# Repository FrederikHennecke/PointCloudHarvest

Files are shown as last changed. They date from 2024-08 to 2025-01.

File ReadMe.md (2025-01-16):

# PointCloudHarvest (FarmBot Stereo-Vision Camera Module for Leaf Angle Calculation)

## Motivation
Leaf inclination angles (LIA) are crucial for regulating various processes within the plant carbon–water–energy nexus. In agriculture, these processes include photosynthesis, leaf temperature, plant growth, and the microclimate within the canopy. Despite its significance, LIA remains one of the most understudied plant functional traits due to the difficulty of measuring it accurately, particularly at short temporal intervals. In optical remote sensing, LIA is a key factor influencing spectral variability, which directly impacts the robustness of empirical models. We developed a novel and automated approach to capture 3D point clouds of small crops (e.g., sugar beet), enabling precise determination of LIA from the generated data. Our system, controlled by publicly available code, allows for customizable capture intervals and positions. The method was validated using a 3D-printed sugar beet model with known LIA, demonstrating its potential for advancing plant trait studies.

farmbot

This project implements a module for the FarmBot that uses a stereo-vision camera to take point clouds of sugar beet plants and calculate their leaf angles. The module consists of scripts for recording plant data and generating point clouds from these recordings.

## Project Structure

- [`record/`](record/): Contains Python for recording the plants.
- [`reconstruction_system/`](reconstruction_system/): Contains Python files for creating point clouds from the recordings.
- [`farmbot_files`](farmbot_files/): Contains LUA files. Add the file to the FarmBot web interface.
- [`data/`](data/): Contains example point clouds each generated with this project.
- [`images/`](images/): Contains images used in this repository.
- [`printing_files/`](printing_files/): Contains CAD files used for the project. May be used to 3d print the camera bracket.

## Build Instructions
See [`hardware-setup.md`](hardware-setup.md)).

## Installation

Each folder ([`record/`](record/), [`reconstruction_system/`](reconstruction_system/), [`farmbot_files`](farmbot_files/)) has it's own installation instructions.

## Usage

### Recording Plant Data

- Navigate to the [`record/`](record/) directory and run the appropriate scripts on the camera module (Raspberry Pi).
- Navigate to the [`farmbot_files`](farmbot_files/) directory and copy the LUA file to the farmbot web interface.

### Generating Point Clouds

Navigate to the [`reconstruction_system/`](reconstruction_system/) directory and run the scripts to create point clouds from the recordings.

## Acknowledgements

Many files from the [Open3D documentation](http://www.open3d.org/docs/release/) were used in this project.

## License

This project is licensed under the MIT License - see the [LICENSE](LICENSE) file for details.

## Citation

Please cite [our work](https://doi.org/10.1016/j.mex.2025.103169) if you use this software.
```bibtex
@article{Hennecke_Modification_of_an_2025,
    author  = {Hennecke, Frederik and Bömer, Jonas and Heim, René H.J.},
    doi     = {10.1016/j.mex.2025.103169},
    journal = {MethodsX},
    month   = jan,
    title   = {{Modification of an Automated Precision Farming Robot for High Temporal Resolution Measurement of Leaf Angle Dynamics using Stereo Vision}},
    url     = {http://dx.doi.org/10.1016/j.mex.2025.103169},
    year    = {2025}
}
```

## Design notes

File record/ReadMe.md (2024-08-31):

# RealSense Angle Measurement Software

This software is designed to capture and analyze angles using a RealSense camera on a Raspberry Pi.

## Prerequisites

### Librealsense

Librealsense is a cross-platform library for capturing data from Intel RealSense depth cameras.

To install Librealsense, follow these steps:

1. Install the prerequisites:

   - On Ubuntu:
     ```bash
     sudo apt-get update && sudo apt-get upgrade
     sudo apt-get install git cmake libssl-dev libusb-1.0-0-dev pkg-config libgtk-3-dev
     ```

   - On Windows:
     Download and install [Visual Studio](https://visualstudio.microsoft.com/) and [CMake](https://cmake.org/download/).

2. Clone the librealsense repository:

   ```bash
   git clone https://github.com/IntelRealSense/librealsense.git
   cd librealsense
   ```

3. Build and install the library:

   - On Ubuntu:
     ```bash
     mkdir build && cd build
     cmake ../ -DBUILD_EXAMPLES=true
     make && sudo make install
     ```

   - On Windows:
     Follow the instructions in the `librealsense` [documentation](https://github.com/IntelRealSense/librealsense/blob/master/doc/installation_windows.md).

### Python

1. **Install Python 3**: Ensure Python 3 is installed on your Raspberry Pi.

2. **Install RealSense Library**:
   - You need to install the RealSense library (`librealsense2`) on your Raspberry Pi.
   - Follow the official [Intel RealSense installation guide](https://github.com/IntelRealSense/librealsense/blob/master/doc/installation.md) for instructions specific to your platform.

3. **Install Python Dependencies**:
   - After installing `librealsense2`, install the required Python dependencies. This includes the RealSense Python wrapper.

   ```bash
   pip install opencv-python
   pip install pyrealsense2
   ```

## Installation

1. **Clone the Repository**:
   - Download the software to your Raspberry Pi by cloning the repository or copying the files.

   ```bash
   git clone <repository-url>
   cd <repository-directory>
   ```

2. **Run the Software**:
   - To start capturing and analyzing angles, run the `main.py` script.

   ```bash
   python3 main.py
   ```

## Usage

Once the software is running, it will automatically begin capturing depth images, whenever it gets a signal via UART.

## Troubleshooting

- Ensure that the RealSense camera is properly connected to the Raspberry Pi.
- Make sure `librealsense2` and `pyrealsense2` are correctly installed.
- If you encounter any errors, check the dependencies and ensure all required libraries are installed.

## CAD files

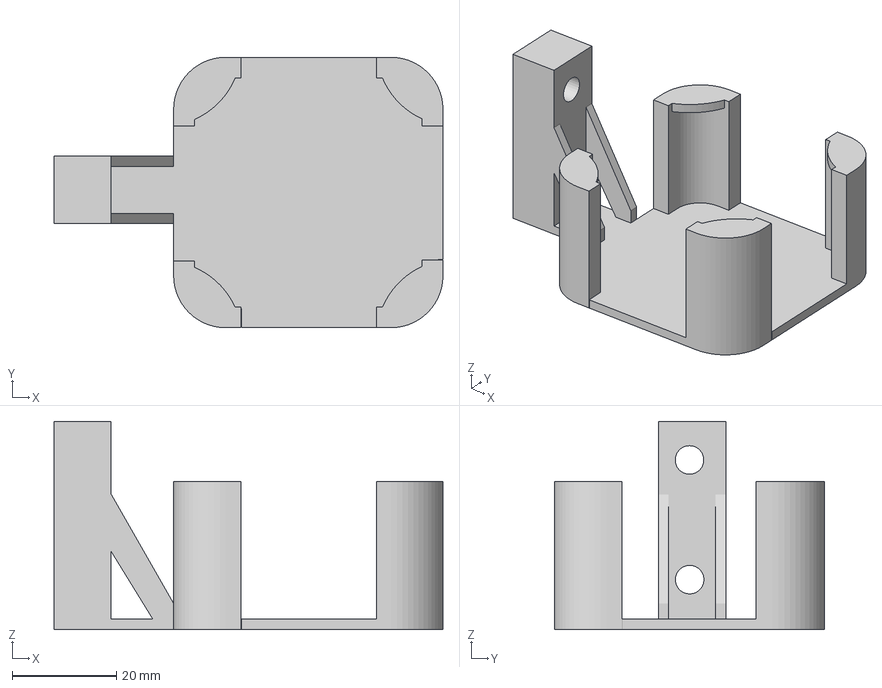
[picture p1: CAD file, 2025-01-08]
printing_files/D405_Bracket.3mf
74.8 x 52.0 x 40.0 mm

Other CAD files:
data/1_3.ply
data/1_2.ply
data/6_2.ply
data/1_1.ply
data/3_2.ply
data/3_3.ply
data/6_1.ply
data/6_3.ply
data/3_1.ply
printing_files/D405_Bracket.f3d

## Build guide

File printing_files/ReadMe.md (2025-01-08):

The CAD files of the Realsense D405 camera can be found on the [official intel realsense website](https://dev.intelrealsense.com/docs/stereo-depth-camera-d400#section-cad-files).

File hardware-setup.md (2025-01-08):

# List of Materials
- Any [FarmBot](https://farm.bot/)
- [Raspberry Pi 4b 8GB](https://www.raspberrypi.com/products/raspberry-pi-4-model-b/?variant=raspberry-pi-4-model-b-8gb) - not the one from the FarmBot, but a different one
  - Raspberry Pi Mount (see [here](https://a.co/d/2Kd7VHw) for a waterproof container)
  - micro-SD 64GB
  - Any power supply for the Raspberry Pi like the USB-C supply.
- [Intel Realsense D405](https://www.intelrealsense.com/depth-camera-d405/)
  - Long USB cable (D405 needs a [Micro B](https://amzn.eu/d/33nk2e9)) for the camera. Should be at least 2m for a 1.5m FarmBot.
  - Camera Mount (see [`printing_files/`](printing_files/))
- External SSD (with USB connector) for saving all depth images.
- Cable to connect the Raspberry Pi UART
  - Ex: female to female jumper wire
  - Length is dependent on your mount location of the Raspberry Pi

# Setup
farmbot
1. Build the FarmBot
   - While adding the cables to the cable carries of the cross-slide and z-axis, also add the USB cable to the carries.
2. Add the camera to the main gantry using the camera mount.
   - It should face downward. It can have an offset.
   - Connect the camera to the USB cable previously installed.
3. Add the Raspberry Pi with its mount.
4. Connect the Raspberry Pi to the USB cable and to the PSU.
5. Connect the Raspberry Pi to the Raspberry Pi in the electronics box of the FarmBot via UART.
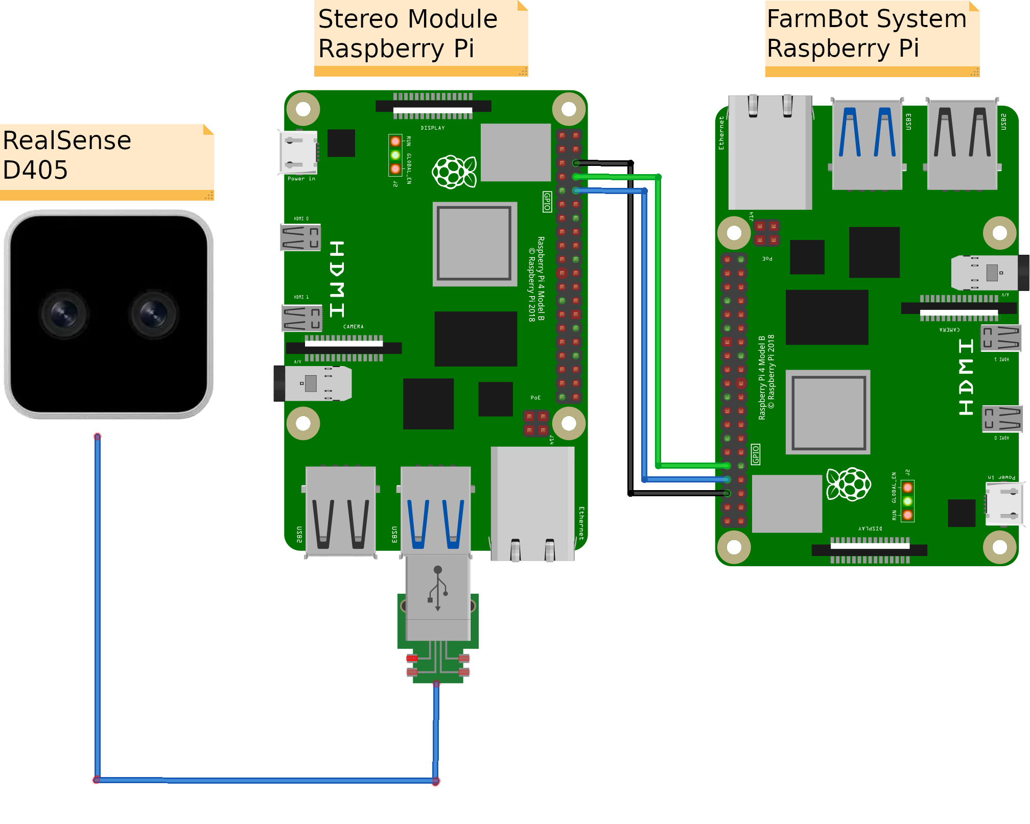
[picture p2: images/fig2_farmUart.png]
UART

6. Install any OS on the micro-SD card (Raspian is recommended).
7. Put the micro-SD card into the Raspberry Pi.
8. Connect the external SSD to the Raspberry Pi.
9. Connect the Raspberry Pi to its power supply.
10. Mount the SSD ([see](https://raspberrypi-guide.github.io/filesharing/mounting-external-drive)).
11. Follow the software installation instruction in [`reconstruction_system/`](reconstruction_system/) and [`farmbot_files`](farmbot_files/).

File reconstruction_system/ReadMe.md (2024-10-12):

# Open3D Reconstruction System

This software provides a flexible system for reconstructing 3D models from RGBD sequences using Open3D. You can control various stages of the reconstruction process through command-line arguments.

## Prerequisites

1. **Install Python 3**: Ensure Python 3 is installed on your system.

2. **Install Required Libraries**:
   - Install Open3D and other necessary Python libraries:

   ```bash
   pip install opencv-python
   pip install open3d
   ```
(See [here](https://www.open3d.org/docs/release/getting_started.html) for help using Open3D)
## Installation

1. **Clone the Repository**:
   - Download the software to your local machine:

   ```bash
   git clone <repository-url>
   cd <repository-directory>
   ```

2. **Install the Software**:
   - If there are any additional setup steps or dependencies, follow the instructions provided in the repository.

## Usage

```bash
python3 main.py [OPTIONS]
```

### Available Arguments

- `--config`:
  - **Optional**: Path to the configuration file.
  - **Default**: `None`

- `--default_dataset`:
  - **Optional**: Dataset to be used if no config file is provided.
  - **Options**: `lounge`, `bedroom`, `jack_jack`
  - **Default**: `lounge`

- `--make`:
  - **Optional**: Generate fragments from the RGBD sequence.
  
- `--register`:
  - **Optional**: Register all fragments and detect loop closures.
  
- `--refine`:
  - **Optional**: Refine the rough registrations of fragments.
  
- `--integrate`:
  - **Optional**: Integrate the entire RGBD sequence to create the final mesh.
  
- `--slac`:
  - **Optional**: Run SLAC optimization on fragments (if using SLAC).
  
- `--slac_integrate`:
  - **Optional**: Integrate fragments using SLAC to create the final point cloud or mesh.
  
- `--debug_mode`:
  - **Optional**: Enable debug mode for detailed logs and troubleshooting.
  
- `--device`:
  - **Optional**: Select the processing device for SLAC and SLAC integration.
  - **Example**: `cpu:0`, `cuda:0`
  - **Default**: `cpu:0`
  
- `--multiple`:
  - **Optional**: Reconstruct multiple recordings from the specified dataset path.
  - **Example**: `../dataset/`

### Example Commands

1. **Run reconstruction with default settings**:

   ```bash
   python3 main.py --config config/realsense.json --make --register --refine --integrate
   ```

2. **Run reconstruction with SLAC optimization and GPU acceleration**:

   ```bash
   python3 main.py --config config/realsense.json --make --register --refine --integrate --slac --slac_integrate --device cuda:0
   ```

3. **Run reconstruction multiple times with given file path**:

   ```bash
   python run_system.py --config config/realsense.json --make --register --refine --integrate --slac --slac_integrate --multiple "../dataset/"
   ```

## Troubleshooting

- **Ensure all dependencies are installed**: Verify that Open3D and any additional libraries are correctly installed.
- **Check your dataset paths and config file**: Make sure paths are correctly specified and accessible.
- **Consult logs**: If encountering issues, review the debug logs if `--debug_mode` is enabled.

## Citation
Thanks to the Open3D project.
```bibtex
@article{Zhou2018,
    author    = {Qian-Yi Zhou and Jaesik Park and Vladlen Koltun},
    title     = {{Open3D}: {A} Modern Library for {3D} Data Processing},
    journal   = {arXiv:1801.09847},
    year      = {2018},
}```

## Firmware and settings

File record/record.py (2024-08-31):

import threading
import pyrealsense2 as rs
import numpy as np
import cv2
from os import makedirs
from os.path import exists, join, abspath
import shutil
import json

import sys

sys.path.append(abspath(__file__))


def make_clean_folder(path_folder):
    """
    delete folder and make a new one (to clean up old data)
    :param path_folder: file path
    :return:
    """
    if not exists(path_folder):
        makedirs(path_folder)
    else:
        shutil.rmtree(path_folder)
        makedirs(path_folder)


def save_intrinsic_as_json(filename, frame):
    """
    save the current intrinsics
    :param filename: JSON file path
    :param frame: realsense frame object to get the current intrinsics
    :return:
    """
    intrinsics = frame.profile.as_video_stream_profile().intrinsics
    with open(filename, 'w') as outfile:
        json.dump(
            {
                'width':
                    intrinsics.width,
                'height':
                    intrinsics.height,
                'intrinsic_matrix': [
                    intrinsics.fx, 0, 0, 0, intrinsics.fy, 0, intrinsics.ppx,
                    intrinsics.ppy, 1
                ]
            },
            outfile,
            indent=4)


class recorder:
    """
    class to start / stop recording RGBD images
    """

    def __init__(self):
        self.run = False
        self.thread = None

    def start(self, path_output="../dataset/"):
        """
        start recording RGBD images
        :param path_output: file path to save output
        :return:
        """
        if not self.run:
            self.run = True
            self.thread = threading.Thread(target=self._rec, kwargs={"path_output": path_output})
            self.thread.start()
        else:
            self.stop()
            self.start()

    def _rec(self, path_output, show_window=False):
        """
        :param path_output: file path to save output
        :param show_window: debug option to show currently seen depth image
        :return:
        """
        self.run = True

        path_depth = join(path_output, "depth")
        path_color = join(path_output, "color")

        # record imgs
        make_clean_folder(path_output)
        make_clean_folder(path_depth)
        make_clean_folder(path_color)

        # Create a pipeline
        pipeline = rs.pipeline()

        jsonObj = json.load(open("camSettings.json"))
        json_string = str(jsonObj["parameters"]).replace("'", '\"')

        # Create a config and configure the pipeline to stream
        #  different resolutions of color and depth streams
        config = rs.config()
        config.enable_stream(rs.stream.depth, int(jsonObj['viewer']['stream-width']),
                             int(jsonObj['viewer']['stream-height']),
                             rs.format.z16, int(jsonObj['viewer']['stream-fps']))
        config.enable_stream(rs.stream.color, int(jsonObj['viewer']['stream-width']),
                             int(jsonObj['viewer']['stream-height']),
                             rs.format.bgr8, int(jsonObj['viewer']['stream-fps']))
        cfg = pipeline.start(config)
        dev = cfg.get_device()

        advnc_mode = rs.rs400_advanced_mode(dev)
        advnc_mode.load_json(json_string)

        # Start streaming
        depth_sensor = cfg.get_device().first_depth_sensor()

        # Getting the depth sensor's depth scale (see rs-align example for explanation)
        depth_scale = depth_sensor.get_depth_scale()

        # We will not display the background of objects more than
        #  clipping_distance_in_meters meters away
        clipping_distance_in_meters = 3  # 3 meter
        clipping_distance = clipping_distance_in_meters / depth_scale

        # Create an align object
        # rs.align allows us to perform alignment of depth frames to others frames
        # The "align_to" is the stream type to which we plan to align depth frames.
        align_to = rs.stream.color
        align = rs.align(align_to)

        # Streaming loop
        frame_count = 0
        try:
            while True:
                # Get frameset of color and depth
                frames = pipeline.wait_for_frames()

                # Align the depth frame to color frame
                aligned_frames = align.process(frames)

                # Get aligned frames
                aligned_depth_frame = aligned_frames.get_depth_frame()
                color_frame = aligned_frames.get_color_frame()

                # Validate that both frames are valid
                if not aligned_depth_frame or not color_frame:
                    continue

                depth_image = np.asanyarray(aligned_depth_frame.get_data())
                color_image = np.asanyarray(color_frame.get_data())

                if frame_count == 0:
                    save_intrinsic_as_json(
                        join(path_output, "camera_intrinsic.json"),
                        color_frame)

                cv2.imwrite("%s/%06d.png" % (path_depth, frame_count), depth_image)
                cv2.imwrite("%s/%06d.jpg" % (path_color, frame_count), color_image)
                print("Saved color + depth image %06d" % frame_count)
                frame_count += 1

                # Remove background - Set pixels further than clipping_distance to grey
                grey_color = 153
                # depth image is 1 channel, color is 3 channels
                depth_image_3d = np.dstack((depth_image, depth_image, depth_image))
                bg_removed = np.where((depth_image_3d > clipping_distance) | \
                                      (depth_image_3d <= 0), grey_color, color_image)

                # Render images
                depth_colormap = cv2.applyColorMap(
                    cv2.convertScaleAbs(depth_image, alpha=0.09), cv2.COLORMAP_JET)
                images = np.hstack((bg_removed, depth_colormap))

                if show_window:
                    cv2.namedWindow('Recorder Realsense', cv2.WINDOW_AUTOSIZE)
                    cv2.imshow('Recorder Realsense', images)
                    cv2.waitKey(1)

                if not self.run:
                    cv2.destroyAllWindows()
                    break

        except Exception as e:
            print(e)
        finally:
            pipeline.stop()
            # send uart message

    def stop(self):
        """
        stop recording
        :return:
        """
        if self.run:
            self.run = False
            self.thread.join()  # Wait for the thread to finish


if __name__ == "__main__":
    app = recorder()

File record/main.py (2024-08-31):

import serial
import time

import pyrealsense2 as rs
import numpy as np
import cv2
import record


def write_message(string: str, ser: serial.Serial):
    if not string:
        return
    try:
        string = string.encode("utf_8")
        ser.write(string)
    except Exception as error:
        print("error sending message: ", error)


if __name__ == '__main__':
    # if connected via serial Pin(RX, TX)
    ser = serial.Serial('/dev/ttyS0', 9600, timeout=1)  # 9600 is baud rate(must be same with that of NodeMCU)
    ser.flush()
    rec = record.recorder()
    while True:
        try:
            line = ser.readline().decode("UTF-8").strip()
            if line:
                print(line)
                if line.strip() == "stop":
                    rec.stop()
                    write_message("f", ser)
                else:
                    print("received: ", line)
                    if line.strip().startswith("f_"):
                        rec.start(line.strip())
                    else:
                        print("error parsing line")
                        rec.stop()
        except:
            print("Error while parsing message")
        time.sleep(1)  # delay of 1 second

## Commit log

2024-10-10 added example files
    [1_1.ply, 1_2.ply, 1_3.ply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]
2024-10-12 updated reconstruction settings + smaller pointcloud files
    [1_1.ply, 1_2.ply, 1_3.ply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]
2025-01-08 added more instructions to the ReadMe
    [D405_Bracket.3mf, D405_Bracket.f3d]
